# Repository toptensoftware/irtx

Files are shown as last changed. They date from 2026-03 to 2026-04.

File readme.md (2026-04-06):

# irtx

An open source flexible firmware for ESP32 based Infrared transmitter/receivers.

irtx can act as a dumb blaster:

* Receive IR commands over UDP and transmit using an attached IR transmitter circuit
* Accept either raw timing data, or NEC or Panasonic encoded values
* Pair with up to 4 BLE devices to send keyboard, mouse or consumer control HID packets

irtx can also act as a smart device listening for particular actions and invoking actions

* Decode and match received IR signals (supports NEC and Panasonic protocols)
* Handle input events from GPIO attached buttons and rotary encoders
* Invoke sequences of operations in response to IR or GPIO input actions
* Manage a set of "activities" and switch between them

Configuration by serial, telnet or web.

An accompanying NodeJS library [irtx-node](https://github.com/toptensoftware/irtx-node) can 
be used to programatically control the device (eg: send IR codes).  It also provides
a command line tool for sending IR codes and compiling and uploading activity definitions.

## Devices

* [`blaster`](./blaster) - a simple dumb IR blaster that can be placed inconspicously at the back of a room
  providing a way to blast IR from any Wifi enabled device.

## Building the Firmware

The firmware for the esp32 is an Arduino project.  To build

1. Install the `arduino-cli` tools

2. Install the board

    ```bash
    arduino-cli core update-index --additional-urls https://raw.githubusercontent.com/espressif/arduino-esp32/gh-pages/package_esp32_index.json
    arduino-cli core install esp32:esp32 --additional-urls https://raw.githubusercontent.com/espressif/arduino-esp32/gh-pages/package_esp32_index.json
    ```

3. Install libraries

    ```bash
    arduino-cli lib install "Adafruit NeoPixel"
    arduino-cli config set library.enable_unsafe_install true
    arduino-cli lib install --git-url https://github.com/h2zero/NimBLE-Arduino#nvs-custom-namespace
    #arduino-cli lib install "NimBLE-Arduino"
    ```

    (currently requires a dev branch build of NimBLE)

4. Build

    ```bash
    ./build --build c3
    ```

5. Flash (replace com8 with your serial port)

    ```bash
    ./build --flash c3 com8
    ```

Alternatively, you can build and flash in one command:

```
./build c3 com8
```

The firmware also supportes esp32-c6 by passing "c6" instead of "c3" to the build command.

## Activities

Besides acting as a dumb IR blaster, irtx can also manage a set of "activities". 

The activities system supports:

* A set of devices each with a list of operations for turning the device on and off
* A set of activities each of which defines 
    - a set of required devices (which will be turned on, others will be turned off) 
    - a set of operations to and invoke when the activity is switch to, and away from
    - a set of bindings that map input actions (GPIO or received IR commands) to a 
      sequence of operations.

Available operations include:

- Send an IR code
- Send a Wake on Lan packet
- Make an HTTP GET or POST request
- Send a UDP packet
- Delay
- Set the onboard LED
- Switch activities
- Search for a string in a HTTP GET response
- Perform a conditional set of instructions depending on string match

Unlike device configuration which is done via the console and stored in NVS on the device, activity
definitions are compiled from JSON like definitions and uploaded as binary packed data.

The activity definitions can edited either:

* directly in the web UI, or http://my-irtx/activity-editor
* compiled and uploaded using the [node-irtx](https://github.com/toptensoftware/irtx-node) command line tool.

eg: 
```
npx toptensoftware/irtx-node -h my-irtx activites my-activities.js
```

Here's an example activities configuration file (intended for illustration only)

```js
import { op } from "irtx:binpack";

// IR Codes
let ircodes = {
    tvOn: "NEC:0x20dfb34c",
    tvOff: "NEC:0x20dfa35c",
    volumeUp: "PANA:0x400401000405",
    volumeDown: "PANA:0x400401008485",
    ///etc...
}

// Base URL for Yamaha receiver
const yamaUrl = "http://10.1.1.125/YamahaExtendedControl/v1";

// Main Config
const confg = {
    version: 1,
    devices: [
        { 
            // TV Device
            name: "tv", 
            turnOn: op.sendIr(ircodes.tvOn),
            turnOff: op.sendIr(ircodes.tvOff)
        },
        {
            // Yamaha Receiver Device
            name: "receiver", 
            turnOn: op.httpGet(yamaUrl + "/main/setPower?power=on"),
            turnOff: op.httpGet(yamaUrl + "/main/setPower?power=standby"),
        }
    ],
    activities: [
        {
            name: "off",
            devices: [ /* no devices, turn everything off */ ],
        },
        {
            // Watch TV activity
            name: "watchTv",

            // Required devices
            devices: [ "tv", "receiver", ],

            // Actions to invoke when this activity is activated/deactivated
            //didDeactivate: [ ],
            didActivate: op.httpGet(yamaUrl + "/main/setInput?input=hdmi1"),
            //willActivate: [ ],
            //willDeactivate: [ ],

            // Bindings
            bindings: [
                {
                    // Volume up
                    on: ircodes.volumeUp,
                    do: op.httpGet(recUrl +"/main/setVolume?volume=up"),
                },
                {
                    // Volume down
                    on: ircodes.volumeDown,
                    do: op.httpGet(recUrl +"/main/setVolume?volume=down"),
                },
            ]
        },
        {
            // Activity 2 etc...
        }
    ]
}

// The root configuration must be the default export
export default config;

```

## Writing `activities.js`

Activity configurations are written as ES module JavaScript files.  They can be edited
directly in the built-in web UI at `http://<device>/activity-editor`, or compiled to binary
locally using the `@toptensoftware/binpack` tool (or the `irtx-node` CLI which wraps it).

### Importing helpers

The `binpack.js` schema file (served from the device at `/binpack.js` and mapped to the
module specifier `irtx:binpack` by the toolchain) exports everything you need:

```js
import { op, binding, repeatBehaviour, irEventKindMask, bindingFlags,
         riff, parseIPv4, parseMacAddress } from "irtx:binpack";
```

### File structure

An `activities.js` file must default-export the root configuration object:

```js
export default {
    version: 1,
    devices: [ /* device definitions */ ],
    activities: [ /* activity definitions */ ],
};
```

### Devices

Each device has a name and optional `turnOn` / `turnOff` op sequences.  When switching
activities, the firmware powers devices on and off automatically based on which devices the
old and new activities reference.

```js
devices: [
    {
        name: "tv",
        turnOn:  op.sendIr("NEC:0x20dfb34c"),
        turnOff: op.sendIr("NEC:0x20dfa35c"),
    },
    {
        name: "receiver",
        turnOn:  op.httpGet("http://10.1.1.125/YamahaExtendedControl/v1/main/setPower?power=on"),
        turnOff: op.httpGet("http://10.1.1.125/YamahaExtendedControl/v1/main/setPower?power=standby"),
    },
]
```

`turnOn` and `turnOff` accept either a single op or an array of ops.

### Activities

Each activity declares the devices it needs and optional lifecycle hooks:

```js
activities: [
    {
        name: "off",
        devices: [],               // all devices powered off
    },
    {
        name: "watchTv",
        devices: ["tv", "receiver"],   // referenced by name; others are powered off

        // Lifecycle hooks — single op or array of ops, all optional
        willActivate:   [ /* ops run before devices are powered */ ],
        didActivate:    op.httpGet("http://10.1.1.125/.../main/setInput?input=hdmi1"),
        willDeactivate: [ /* ops run before devices are powered down */ ],
        didDeactivate:  [ /* ops run after leaving this activity */ ],

        bindings: [ /* see below */ ],
    },
]
```

Lifecycle order when switching from A → B:
`A.willDeactivate` → `B.willActivate` → device power changes → `B.didActivate` → `A.didDeactivate`

### Bindings

A binding maps an input event (`on`) to a sequence of ops (`do`):

```js
bindings: [
    {
        on: binding.ir("NEC:0x20df40bf"),         // trigger
        do: op.httpGet("http://...?volume=up"),   // single op or array of ops
    },
]
```

The optional `flags` field accepts values from `bindingFlags`:

| Flag | Meaning |
|---|---|
| `bindingFlags.continue_routing` | Don't stop after this binding fires; continue checking remaining bindings |

#### `binding.ir(code)`

Matches a received IR code.  The `code` string format is:

- `"PROTOCOL:VALUE"` — e.g. `"NEC:0x20df40bf"`, `"PANA:0x400401000405"`
- `"PROTOCOL:MODIFIER+VALUE"` — fires only when `MODIFIER` was received within the last 5 s
- `"*"` — wildcard, matches any received IR code

The returned object can be extended with extra fields:

| Field | Default | Description |
|---|---|---|
| `eventMask` | `press` | Bitmask of `irEventKindMask` values to match |
| `minHoldTime` | `0` | Minimum hold time in ms before the binding fires (0 = immediate) |
| `repeatRate` | `0` | Synthetic repeat interval in ms (0 = natural IR repeat rate) |

```js
{ on: { ...binding.ir("NEC:0x20df40bf"), eventMask: irEventKindMask.press | irEventKindMask.repeat }, do: ... }
```

#### `binding.gpio(pin)`

Matches a button press on the given GPIO pin number (configured with `gpio <pin> pulldown/pullup`).

Extra fields available on the returned object:

| Field | Default | Description |
|---|---|---|
| `eventMask` | `press` | `irEventKindMask.press`, `.repeat`, `.release` |
| `minHoldTime` | `0` | ms held before firing (0 = immediate) |
| `initialDelay` | `0` | ms after press before first repeat (0 = use repeatRate) |
| `repeatRate` | `0` | Repeat interval in ms (0 = no repeat) |

#### `binding.encoder_inc(pin)` / `binding.encoder_dec(pin)`

Matches rotary encoder clockwise (`_inc`) or counter-clockwise (`_dec`) rotation on the
encoder whose A-pin is `pin`.  The optional `minVelocityPeriod` field (ms, default 0) limits
firing to encoder velocities at or below the given period.

### Operations (`op`)

All ops can be used as a single value or inside an array wherever an op sequence is expected.

#### `op.sendIr(irCode, ipAddr?, repeat?)`

Transmits an IR code locally or forwards it to a remote irtx device via UDP.

- `irCode` — `"PROTOCOL:VALUE"` string, e.g. `"NEC:0x20df40bf"`
- `ipAddr` — IPv4 address string `"10.1.1.x"` or integer (default `0` = transmit locally)
- `repeat` — one of the `repeatBehaviour` constants (default `repeatBehaviour.default`)

`repeatBehaviour` values:

| Constant | Behaviour |
|---|---|
| `repeatBehaviour.default` | Block the op queue until the IR transmitter is free, then send a full code frame |
| `repeatBehaviour.sendRepeat` | If the same code is already in-flight, send a NEC repeat frame and unblock; otherwise block |
| `repeatBehaviour.dropIfBusy` | If the same code is already in-flight, discard and unblock; otherwise block |

#### `op.httpGet(url)`

Makes an HTTP GET request to `url`.

#### `op.httpPost(url)`

Makes an HTTP POST request to `url`.

#### `op.sendWol(macaddr)`

Sends a Wake-on-LAN magic packet to the given MAC address (`"AA:BB:CC:DD:EE:FF"` string or
array of 6 bytes).

#### `op.delay(ms)`

Pauses op-queue execution for `ms` milliseconds.

#### `op.led(color)`

Sets the onboard LED to `color` (a packed 32-bit RGB integer).  The optional `period` and
`duration` fields (set directly on the returned object) control blink period and auto-off time.

#### `op.udp(ip, data)`

Sends a raw UDP packet.  `ip` is an IPv4 address string or integer; `data` is a byte array.

#### `op.switchActivity(indexOrName)`

Switches to another activity, referenced by its zero-based index or by name string.

#### `op.match_string(str)`

Searches the body of the most recent HTTP response for `str`.  Sets an internal boolean
register used by `op.if_true`.  Use `op.wait_http()` before this op to ensure the HTTP
response has been fully received before searching.

#### `op.if_true(trueOps, falseOps)`

Branches on the result of the most recent `op.match_string` call.  `trueOps` and `falseOps`
are each a single op or an array of ops.

#### `op.wait_http()`

Blocks the op queue until the most recent HTTP request completes.

### Helper functions

#### `riff(str)`

Encodes a 4-character ASCII string as a little-endian 32-bit FourCC integer (the format used
for IR protocol IDs).  Pass a string (`"NEC "`, `"PANA"`) or an integer (returned unchanged).

#### `parseIPv4(ip)`

Parses a dotted-decimal IPv4 address string into a 32-bit integer.  Pass a string or integer
(returned unchanged).

#### `parseMacAddress(mac)`

Parses a colon-separated MAC address string into an array of 6 integers.  Pass a string or
array (returned unchanged).

### Constants

| Export | Values |
|---|---|
| `irEventKindMask` | `press` (1), `repeat` (2), `long_press` (4), `release` (8) |
| `repeatBehaviour` | `default` (0), `sendRepeat` (1), `dropIfBusy` (2) |
| `bindingFlags` | `continue_routing` (1) |
| `bindingType` | `ir` (1), `ir_any` (2), `gpio` (3), `gpio_encoder` (4) |
| `opId` | Numeric IDs for all op types (normally accessed via the `op` class helpers) |

## Configuring the Device

Wifi needs to be configured through serial terminal program.  Once Wifi is enabled, all other
configuration can be done through serial, telnet or via the built-in web based terminal.

To setup Wifi, use a serial monitor program (eg: [ttsm](https://github.com/toptensoftware/ttsm)) to configure the device.  Use the `setwifi` command to setup connection to your Wifi network.

Alternatively you can configure the device to act as a Wifi Access Point using the `setap` command, 
however since AP mode can only be entered using a boot pin configuration you also need a physical 
button on the device and it needs to be configured using the `gpio` and `setbootpin` commands.

Once Wifi or AP mode is active, you can use telnet or the built-in web UI to configure the rest
of the device using the console commands described below.

## Console Commands

The following console commands are available via serial, telnet or using the web UI.

 *   `name <devicename>`                  - set device name, takes effect after restart
 *   `setwifi <ssid> <password>`          - configure WiFi credentials and reconnect
 *   `setap <ssid> [<password>]`          - configure access point credentials (default password: `irtx`)
 *   `setbootpin <pin> [<pin>]`           - configure pin(s) that trigger AP mode at boot (see below)
 *   `status`                             - show device name, MAC, WiFi, IP, BLE pairing status
 *   `pair <bleslot>`                     - pair a BLE device with a specified slot
 *   `unpair <bleslot>`                   - unpair a BLE device slot
 *   `connect <bleslot>`                  - connect to the paired device for a slot
 *   `led <r> <g> <b>` / `led clear`     - set or clear the user LED colour
 *   `activity <name|index>`              - switch to an activity by name or index
 *   `setdefact <index>`                  - set the default activity loaded on boot (default: 0)
 *   `gpio [<pin> [<pin>] <mode>]`        - show or configure GPIO pins
 *   `verbose on|off`                     - enable or disable verbose logging (persisted across reboots)
 *   `nvsreset`                           - factory reset
 *   `nvsdump`                            - dump keys in NVS
 *   `reboot`                             - reboot the device
 *   `dmesg`                              - displays the message log (up to 50 past logged messages)
 *   `help`                               - list all commands

## Configuring GPIO Pins

By default, no GPIO pins are configured.

To set the status LED neopixel to GRB format on pin 10 (eg: Waveshare C3 zero dev board)

```
gpio 10 grb
```

To set the status LED neopixel to GRB format on pin 8 (eg: Waveshare C6 WROOM dev board)

```
gpio 8 grb
```

To set the pins the IR receiver (eg pin 5) and transmitter (eg pin 4) are connected:

```
gpio 5 irrx
gpio 4 irtx
```

To set a generic button input with pull down:

```
gpio 11 pulldown
```

To set a rotary encoder input, pass the A/B pin pair:

```
gpio 12 13 pulldown
```

Note: button and encoder inputs don't do anything unless also configured in the activities 
configuration to perform operations.

## Access Point Mode

The device can be started in WiFi access point (AP) mode for configuration via telnet or web without
needing to connect to an existing network.

1. Configure the AP SSID (and optionally a password, default is `irtx1234`):

    ```
    setap mydevice-ap
    ```

2. Configure a GPIO pin that will trigger AP mode when held at boot. The pin should also be configured
   as a pullup or pulldown input using the `gpio` command:

    ```
    gpio 9 pullup
    setbootpin 9
    ```

3. Press the attached button while powering on the device. The status LED (if configured) will turn 
   yellow to confirm AP mode is active.

4. On your computer or phone, connect to the WiFi network matching the AP SSID you configured,
   using the AP password.

5. Either: 
    * telnet to `192.168.4.1` to access the device terminal
    * visit `http://192.168.4.1` and use the console tab 

Two pins can be specified with `setbootpin` — both must be pressed simultaneously at boot to trigger
AP mode (useful to avoid accidental triggers).

## Telnet Support

Once wifi is enabled and working you can use telnet (eg: [ttsm](https://github.com/toptensoftware/ttsm)) to configure and monitor the device using the same commands as above.

Note: only one telnet client can connect at a time.

## Pairing BLE Devices

Up to 4 paired BLE devices are supported, but only one can be active at a time.  To pair a device:

1. Connect using a serial monitor program or telnet
2. Type `pair N` and the device will start advertising itself for pairing (eg: type `pair 0` for the first device)
3. Go to the device to be paired and choose to pair it.
4. You should see connected and authenicated messages in the terminal and then a message 
   saying the device has been paired.
5. Pair subsequent devices by typing `pair 1`, `pair 2` and `pair 3`

To test connection, use the `connect N` command.   The paired device should automatically reconnect if available.  Use
`connect -1` to disconnect all devices.  Once all devices are paired it's recommended to test switching the connection
between all devices to ensure everything is setup correctly.

Use the `unpair N` command to unpair a device - you should also unpair from the other device too. (eg: "forget this device", "remove device")

The `status` command shows the public addresses for each of the virtual pairing slots, the address of any paired device and the
connection status.

Note: BLE can be a bit flakey during pairing.  Sometimes you might need to toggle bluetooth on/off on the device being paired
to get it to initially connect.

## UDP Protocol

The following describes the UDP protocol for communicating with the device.

Node.js clients can use the [irtx-node](https://github.com/toptensoftware/irtx-node) library.

### IR Transmit

To transmit an IR signal, send a UDP packet to port 4210 in the following format:

* `uint16_t cmd` - must be 1
* `uint16_t reserved` - unused (used to be device index)
* `uint32_t carrierFreq` - carrier frequency
* `uint32_t gap` - a trailing gap (see below)
* `uint16_t timingData[]` - IR code timing values

(all values are little endian)

The `cmd` value must be 1 and indicates this is an IR transmission packet

The `carrierFrequency` must be `38000` otherwise the packet is ignored (might add support for others later)

The `gap` value is a minimum time (in microseconds) that the 
device will enforce between the end of one transmission and the start of the next.

The `timingData` is an array of microsecond timing values where event indices are pulses and odd indices are spaces.  If an odd number of values is passed an implicit zero gap is appended.

Note: pronto IR code definitions usually include the `gap` as the last space in the timing data. I recommended to pass that last space timing value as the `gap` parameter and set the trailing timing space to 0.

### Connect BLE Device

Before sending HID packets to a BLE device, the device first needs to be connected:

* `uint16_t cmd` - must be 2
* `uint8_t bleslot` - the BLE virtual device slot to connect

Currently there's no network method to check if the connection succeeded.  Use the serial or telnet monitor to check status manually.

### Send BLE HID Input Report

Once a BLE device is connected, HID reports can be sent

* `uint16_t cmd` - must be 3
* `uint8_t bleslot` - the BLE virtual device slot to connect
* `uint8_t reportId` - the kind of hid report to send
* `uint8_t reportData[]` - the actual HID report

The `reportId` and `reportData[]` should be

* `reportId` = 1, `reportData[8]` - keyboard input report
* `reportId` = 2, `reportData[2]` - consumer control report
* `reportId` = 3, `reportData[4]` - mouse input report

The format of the `reportData` is as per the BLE HID spec.  The length of the report data must be correct
otherwise the packet will be dropped (check serial/telnet monitor if packets are not being delivered).

### Transmit IR Code

To transmit an IR signal using a named protocol, send a UDP packet to port 4210 in the following format:

* `uint16_t cmd` - must be 4
* `uint16_t reserved` - unused (used to be device index)
* `uint32_t protocolId` - identifies the IR protocol (see below)
* `uint64_t code` - the IR code value to transmit
* `uint8_t repeat` - if non-zero, sends the protocol's repeat frame instead of a full code frame

(all values are little endian)

The device encodes `code` according to the named protocol and transmits it.  The trailing gap is determined by the protocol definition.

Supported protocol IDs are 4-character RIFF-style codes:

| Protocol | ID bytes (`protocolId` little-endian) | Bits |
|---|---|---|
| NEC | `4E 45 43 20` (`0x2043454E`) | 32 |
| Panasonic  | `50 41 4E 41` (`0x414E4150`) | 48 |

If `repeat` is non-zero and the protocol defines a repeat frame, the repeat frame is sent instead of encoding `code`.  NEC defines a repeat frame; Panasonic does not.

### Switch Activity

Switches the current activity:

* `uint16_t cmd` - must be 5
* `uint32_t activityIndex` - the index of the activity to switch to

### Simulate IR Code

Simulates the receipt of an IR code and dispatches it through the activity system:

* `uint16 cmd` - must be 6
* `uint32 protocol` - riff encoded IR protocol
* `uint64 code` - the IR code
* `uint32` - the event kind  (press, release, see [irEventKindMask](./binpack.js))

## HTTP API

The device runs an HTTP server on port 80. All API endpoints return `text/plain` unless noted.

### `GET /api/status`

Returns a JSON object with the current device status (name, MAC address, WiFi, IP, BLE pairing state). Equivalent to the `status` serial/telnet command.

### `GET /api/dmesg`

Returns the device message log as plain text (up to the last 50 entries). Equivalent to the `dmesg` serial/telnet command.

### `POST /api/command`

Executes a serial/telnet command on the device. The request body is the command string (plain text). Returns the command output as plain text.

```
POST /api/command
Content-Type: text/plain

status
```

### `POST /api/upload?filename=<name>`

Uploads a file and writes it to LittleFS. The file is supplied as a `multipart/form-data` body with a single `file` field. The `filename` query parameter sets the destination path on the device — a leading `/` is added automatically if omitted.

```
POST /api/upload?filename=activities.bin
Content-Type: multipart/form-data; boundary=...
```

### `POST /api/reload-activities`

Reloads `activities.bin` from LittleFS and makes it the active configuration. Call this after uploading a new `activities.bin` via `/api/upload`.

### `GET /<path>`

Serves files in the following priority order:

1. **Built-in web UI** — files compiled into the firmware (gzip-compressed, served from flash)
2. **LittleFS** — user-uploaded files (e.g. `activities.bin`, `activities.js`)
3. **SPA fallback** — `GET`/`HEAD` requests that match no file return `index.html` so the client-side router can handle the URL

MIME types are inferred from the file extension: `.html`, `.css`, `.js`, `.json`, `.txt`, `.xml`, `.bin`, `.png`, `.jpg`/`.jpeg`, `.gif`, `.svg`, `.ico`, `.pdf`, `.gz`, `.zip`. Unknown extensions are served as `application/octet-stream`.

The following files have special meaning:

| File | Location | Description |
|---|---|---|
| `/activities.js` | LittleFS | Source file for the current activity configuration (uploaded for reference) |
| `/activities.bin` | LittleFS | Compiled binary form of `activities.js`, loaded by the firmware at boot and on reload |
| `/binpack.js` | firmware (built-in) | Type definitions used to compile `activities.js` into `activities.bin` (fetched by the CLI at upload time) |

`/activities.js` and `/activities.bin` are kept in sync by the upload workflow — the CLI and web UI both upload both files together and then call `/api/reload-activities`.

## License

This project is licensed under the MIT License - see the [LICENSE](LICENSE) file for details.

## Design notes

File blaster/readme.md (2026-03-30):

# blaster

A simple dumb IR blaster that can be placed inconspicously at the back of a room
providing a way to blast IR from any Wifi enabled device.

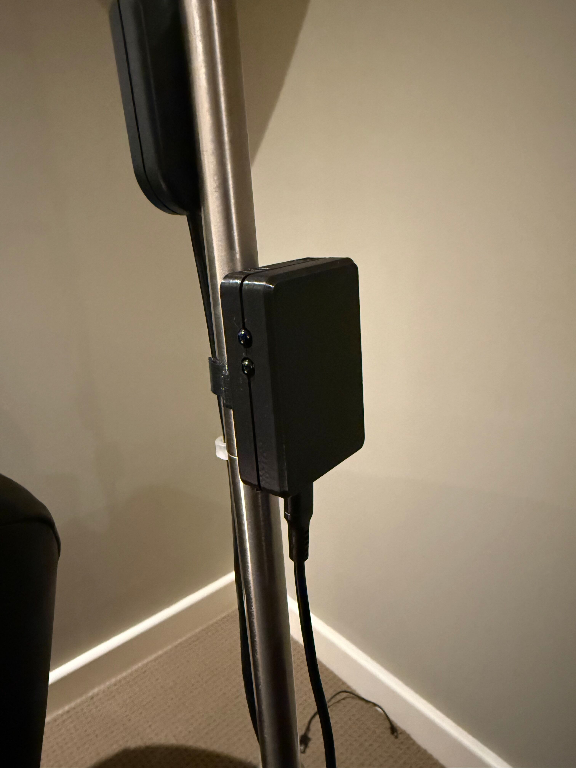
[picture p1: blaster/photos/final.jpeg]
Final


## Build the Circuit

The IR transmitter circuit is easy to build on a small piece of veroboard:

Parts:

* C1 - 100nf ceramic cap
* C2 - 47uF electrolytic cap
* R1 - 680R
* R2 - 22R (or 10R, or 5R)
* BC337 NPN transistor
* 2x IR LEDs (like [these](https://www.jaycar.com.au/5mm-infrared-transmitting-led/p/ZD1945))
* Veroboard 13x8 pins
* [Waveshare ESP32-C3 Zero](https://www.waveshare.com/wiki/ESP32-C3-Zero)

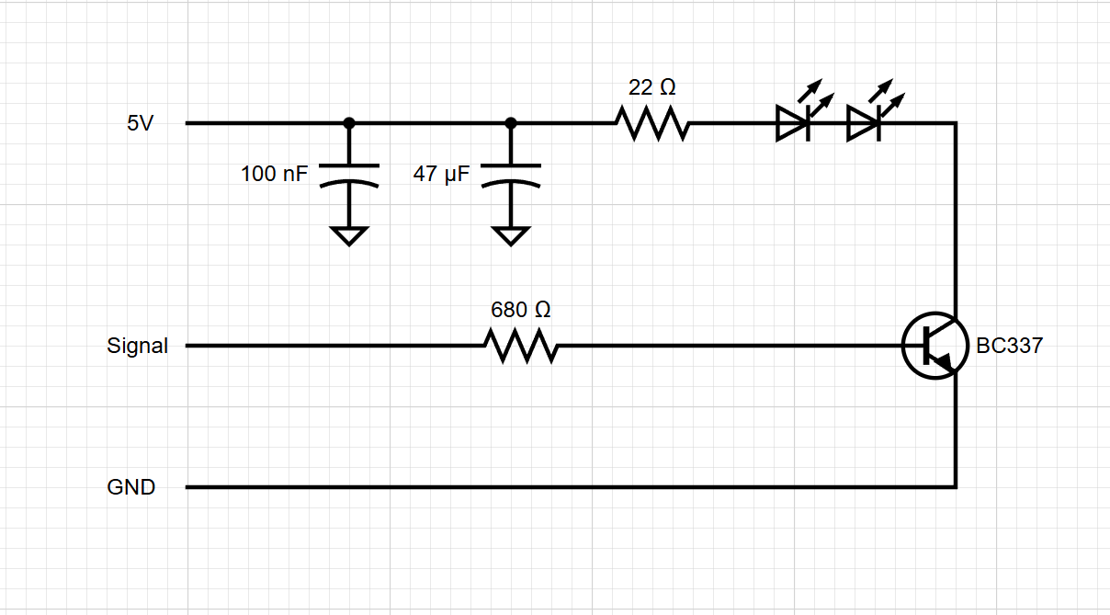
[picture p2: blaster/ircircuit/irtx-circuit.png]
Circuit Diagram


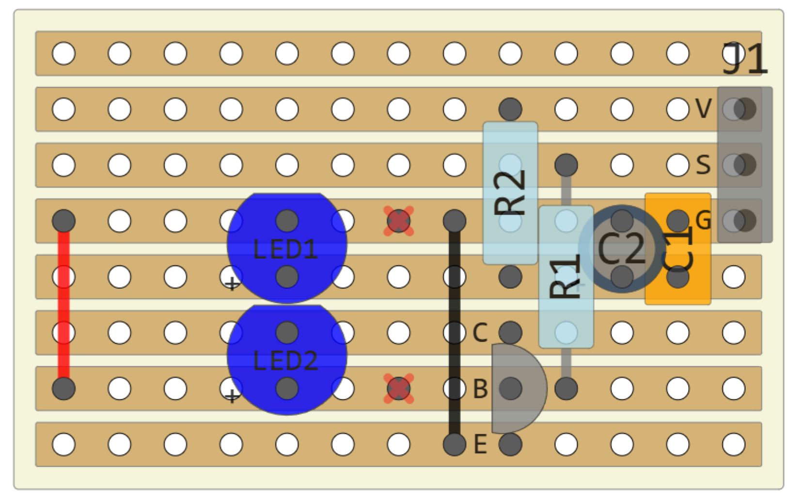
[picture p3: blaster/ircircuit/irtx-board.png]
Veroboard


Notes: 

* the above diagram shows a jumper J1 - it's just for labelling where to solder the wires that go to the ESP32.
* don't forget the two cut tracks indicated by red X
* if I was to rebuild this I'd probably move the red jumper wire at the left to just to the right of the LEDs.
* The leads to C2 need to be bent and the cap "laid down" to fit in the case (see photo below)
* The IR LEDs leads need to be bent so they face out the left side of the diagram. (see photo below)
* Leave the veroboard slightly oversized and file down later to fit the snap-in clips in the case.

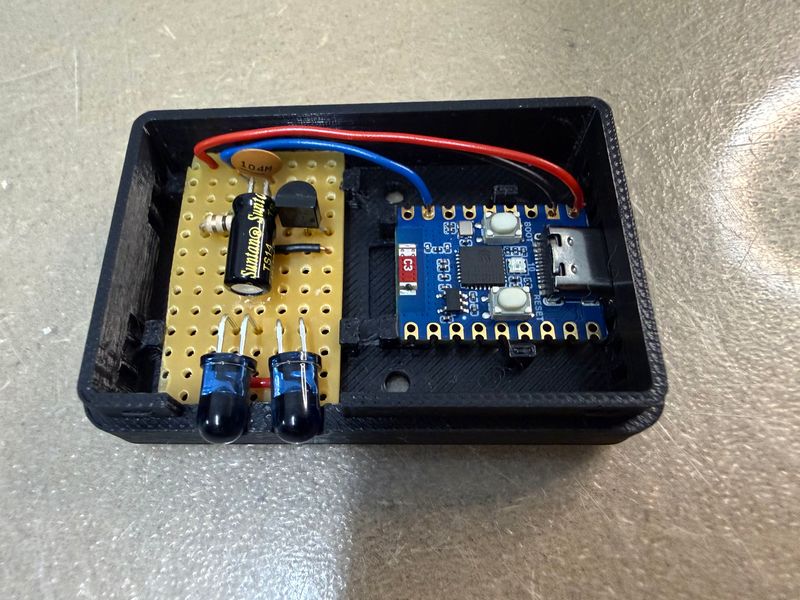
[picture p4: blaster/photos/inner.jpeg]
Inner


## Print the Case

This case supports IR transmitter circuitry only. 

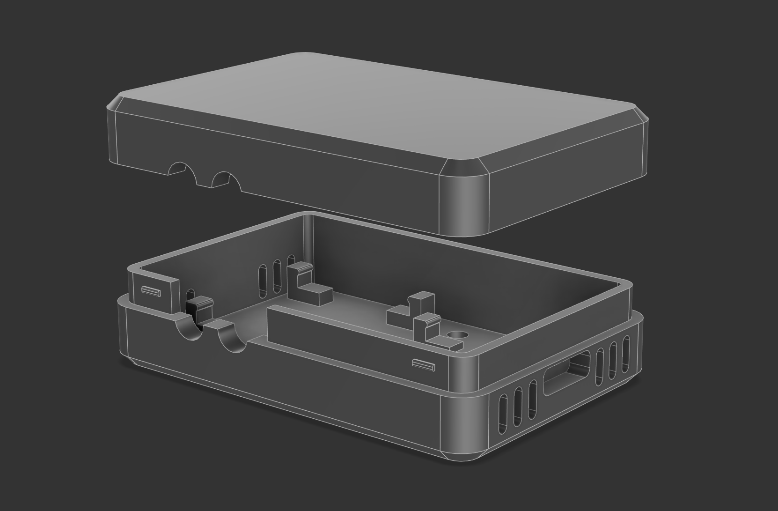
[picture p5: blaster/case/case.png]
case


The case consists of three parts:

* [Top](./case/irtxcase-top.3mf)
* [Bottom](./case/irtxcase-bottom.3mf)
* [Clamp](./case/irtxcase-clamp.3mf)

You'll need a well calibrated printer to get the boards to clip in and the case to snap closed nicely.

The clamp is designed for a 15mm pole and requires:

* two M2.5 heat set inserts 
* two M2.5 6mm screws.

Or, design your own clamp for whereever you want to mount it to. The mounting holds are 26mm center-to-center. 

Fusion and 3mf files are the in the [./case](./case) subdirectory.

I printed the case in PLA, and the clamp in PETG.  You might be able to print it in ABS but I found the board clips too fragile.

## Connect the ESP32

There are three wires from the ESP32 Zero to the IR transmitter circuit.  

* The IR transmitter connection points are shown in the above stripboard image.

* The ESP32 Zero connections are to 5V and GND at the top left and signal to GPIO 4:

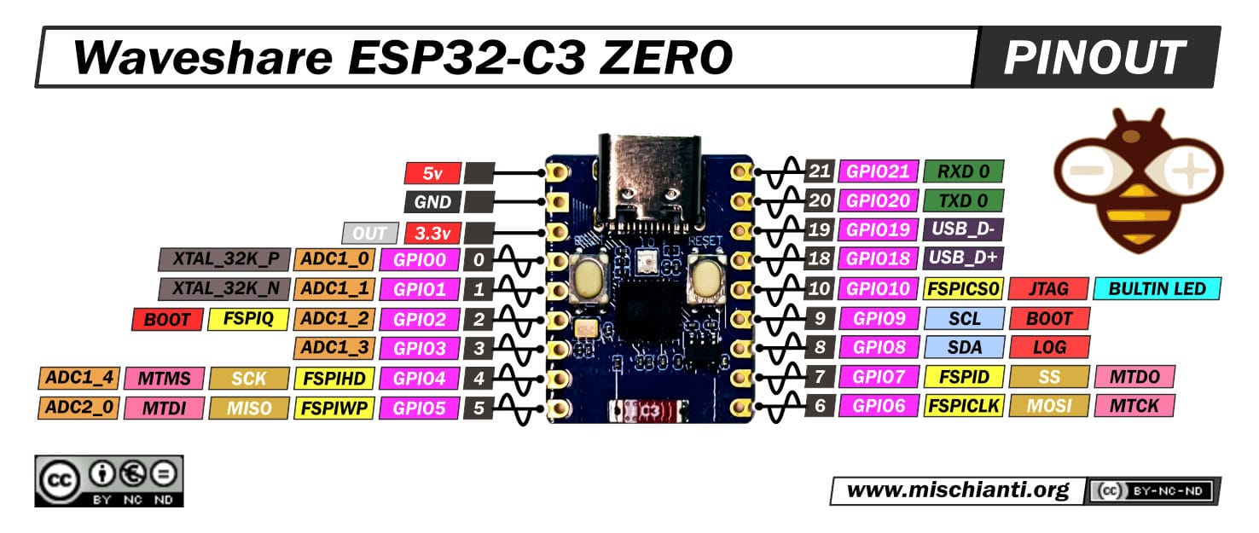
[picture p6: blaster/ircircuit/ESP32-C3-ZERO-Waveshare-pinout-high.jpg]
ESP32-C3-Zero
    

## Configuring the Device

Once the firmware has been built and flashed to the device ([see here](https://github.com/toptensoftware/irtx/#building-the-firmware)) the network
and GPIO pins need to be configured.  Use a serial terminal program (eg: ttsm) to connect
to the device and enter the following commands:

```
setwifi mynetwork mypassword
gpio 10 rgb
gpio 4 irtx
reboot
```

Once rebooted, the onboard LED should show connection status (green if connected).

Test the device by sending IR commands using irtx-node

```
# Send Yamaha receiver power toggle...
npx toptensoftware/irtx-node send NEC:0x7e8154ab
```

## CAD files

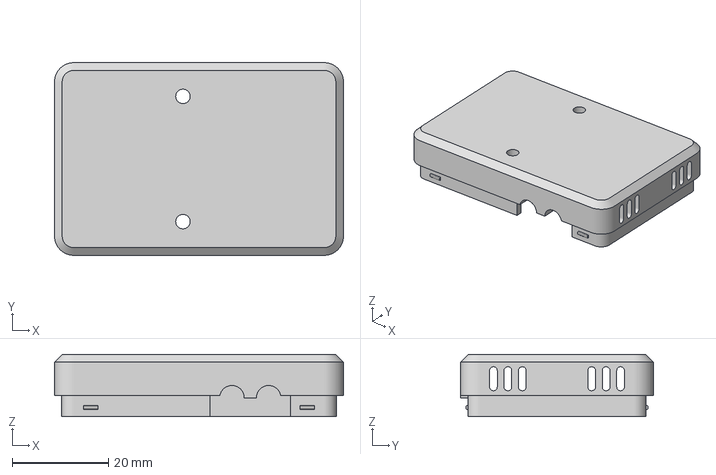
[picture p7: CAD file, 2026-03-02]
blaster/case/irtxcase-bottom.3mf
60.0 x 40.0 x 12.9 mm

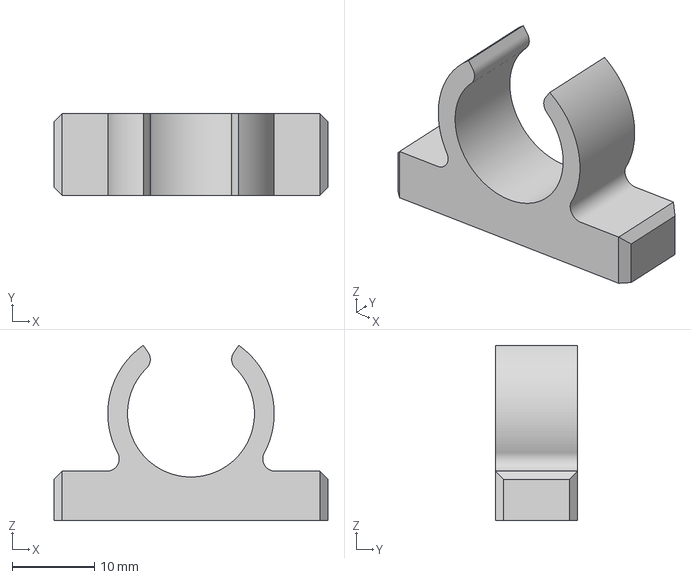
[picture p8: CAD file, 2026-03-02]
blaster/case/irtxcase-clamp.3mf
33.3 x 10.0 x 21.3 mm

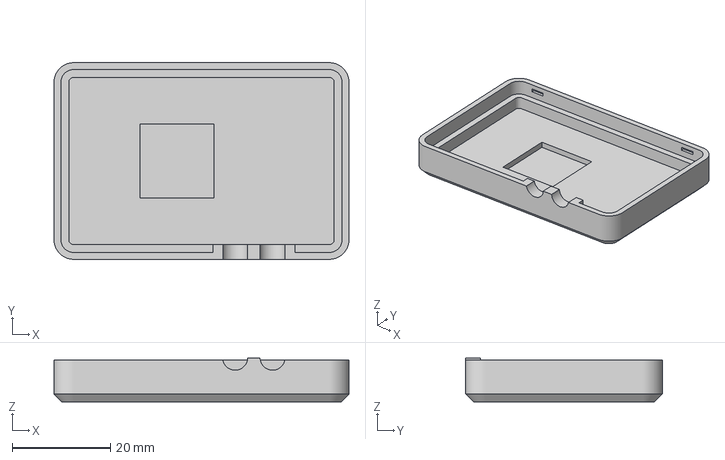
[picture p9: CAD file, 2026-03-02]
blaster/case/irtxcase-top.3mf
60.0 x 40.0 x 8.90 mm

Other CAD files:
blaster/case/irtxcase.f3z

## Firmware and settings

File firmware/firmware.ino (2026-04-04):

/**
 * ESP32 IR Transmitter (WaveShare ESP32-C3 Zero / ESP32-C6)
 *
 * Receives commands over WiFi UDP and either:
 *   - Transmits IR timing sequences via IR LED (RMT peripheral)
 *
 * Hardware:
 *   - IR LED on GPIO 4 (C3) / GPIO 11 (C6)
 *   - Onboard WS2812 RGB LED on GPIO 10 (C3) / GPIO 8 (C6)
 */

#include <WiFi.h>
#include "config.h"
#include "led.h"
#include "device.h"
#include "ir_rx.h"
#include "ir_tx.h"
#include "wifi_udp.h"
#include "console.h"
#include "serial.h"
#include "telnet.h"
#include "ws.h"
#include "ble.h"
#include "filesystem.h"
#include "http.h"
#include "activities.h"
#include "gpio.h"

static SerialConsole  serialConsole;
static TelnetConsole  telnetConsole;
static WsConsole      wsConsole;

void setup()
{
    setLed(LED_PRIORITY_CONNECTIVITY, 0x040200);    // Orange (busy)

    Serial.begin(115200);
    delay(2000);

    // Register consoles before any LOG() calls so output is not lost
    consoleRegister(&serialConsole);
    consoleRegister(&telnetConsole);
    consoleRegister(&wsConsole);

    Serial.println("\n=== ESP32 IR Remote ===");

    setupDeviceName();
    setupGpioConfig();
    setupIrTx();
    setupIrRx();
    setupFs();
    setupActivities();
    setupWifiOrAP();
    setupHttp();
    setupBle();

    // Green = STA connected, Yellow = AP mode
    setLed(LED_PRIORITY_CONNECTIVITY, WiFi.getMode() == WIFI_AP ? 0x040400 : 0x000400);
}

void loop()
{
    serialConsole.poll();
    pollGpio();
    pollIrRx();
    pollIrTx();
    pollWifi();
    pollHttp();
    pollActivities();
    telnetConsole.poll();
    wsConsole.poll();
    pollBle();
}

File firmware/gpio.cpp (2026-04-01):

#include <Arduino.h>
#include "config.h"
#include "gpio.h"
#include "activities.h"

int         gpioIrTxPin    = -1;
int         gpioIrRxPin    = -1;
int         gpioLedPin     = -1;
int         gpioLedOrder   = GPIO_LED_ORDER_GRB;
GpioPinSlot gpioPullupSlots[MAX_GPIO_PULL_PINS]   = {};
uint8_t     gpioPullupCount  = 0;
GpioPinSlot gpioPulldownSlots[MAX_GPIO_PULL_PINS] = {};
uint8_t     gpioPulldownCount = 0;


static void onButton(int pin, bool pressed)
{
    VERBOSE("Button %d %s\n", pin, pressed ? "pressed" : "released");
    invokeGpioBindings(pin, pressed);
}

static void onEncoder(int pin, int direction, uint32_t velocity)
{
    VERBOSE("Encoder %d dir=%+d velocity=%ums\n", pin, direction, velocity);
    invokeEncoderBindings(pin, direction, velocity);
}

// Remove any slot containing pin from both pullup and pulldown lists.
// Also clears irtx/irrx if they match.
static void removePinFromAllRoles(int pin)
{
    if (gpioIrTxPin == pin) gpioIrTxPin = -1;
    if (gpioIrRxPin == pin) gpioIrRxPin = -1;
    if (gpioLedPin  == pin) gpioLedPin  = -1;

    for (int i = 0; i < gpioPullupCount; i++)
    {
        if (gpioPullupSlots[i].pinA == (uint8_t)pin ||
            gpioPullupSlots[i].pinB == (uint8_t)pin)
        {
            memmove(&gpioPullupSlots[i], &gpioPullupSlots[i + 1],
                    (gpioPullupCount - i - 1) * sizeof(GpioPinSlot));
            gpioPullupCount--;
            break;
        }
    }
    for (int i = 0; i < gpioPulldownCount; i++)
    {
        if (gpioPulldownSlots[i].pinA == (uint8_t)pin ||
            gpioPulldownSlots[i].pinB == (uint8_t)pin)
        {
            memmove(&gpioPulldownSlots[i], &gpioPulldownSlots[i + 1],
                    (gpioPulldownCount - i - 1) * sizeof(GpioPinSlot));
            gpioPulldownCount--;
            break;
        }
    }
}

static void saveToNvs()
{
    extern Preferences prefs;
    prefs.begin("gpio", false);
    prefs.putInt("irtx",     gpioIrTxPin);
    prefs.putInt("irrx",     gpioIrRxPin);
    prefs.putInt("led",      gpioLedPin);
    prefs.putInt("ledorder", gpioLedOrder);
    if (gpioPullupCount > 0)
        prefs.putBytes("pullup",   gpioPullupSlots,   gpioPullupCount   * sizeof(GpioPinSlot));
    else
        prefs.remove("pullup");
    if (gpioPulldownCount > 0)
        prefs.putBytes("pulldown", gpioPulldownSlots, gpioPulldownCount * sizeof(GpioPinSlot));
    else
        prefs.remove("pulldown");
    prefs.end();
}

static void initPollState();  // forward declaration — defined below

static void applyPullModes(GpioPinSlot* slots, uint8_t count, int mode)
{
    for (int i = 0; i < count; i++)
    {
        pinMode(slots[i].pinA, mode);
        if (slots[i].pinB != GPIO_PIN_NONE)
            pinMode(slots[i].pinB, mode);
    }
}

void setupGpioConfig()
{
    extern Preferences prefs;
    prefs.begin("gpio", true);
    gpioIrTxPin  = prefs.getInt("irtx",     -1);
    gpioIrRxPin  = prefs.getInt("irrx",     -1);
    gpioLedPin   = prefs.getInt("led",      -1);
    gpioLedOrder = prefs.getInt("ledorder", GPIO_LED_ORDER_GRB);
    size_t upBytes   = prefs.getBytes("pullup",   gpioPullupSlots,
                                      MAX_GPIO_PULL_PINS * sizeof(GpioPinSlot));
    size_t downBytes = prefs.getBytes("pulldown", gpioPulldownSlots,
                                      MAX_GPIO_PULL_PINS * sizeof(GpioPinSlot));
    prefs.end();

    gpioPullupCount   = (uint8_t)(upBytes   / sizeof(GpioPinSlot));
    gpioPulldownCount = (uint8_t)(downBytes / sizeof(GpioPinSlot));

    applyPullModes(gpioPullupSlots,   gpioPullupCount,   INPUT_PULLUP);
    applyPullModes(gpioPulldownSlots, gpioPulldownCount, INPUT_PULLDOWN);
    initPollState();

    LOG("GPIO config: irtx=%d irrx=%d led=%d pullup=%d pulldown=%d\n",
        gpioIrTxPin, gpioIrRxPin, gpioLedPin, gpioPullupCount, gpioPulldownCount);
}

static void printJsonPinArray(GpioPinSlot* slots, uint8_t count)
{
    PRINT("[");
    for (int i = 0; i < count; i++)
    {
        if (i > 0) PRINT(", ");
        if (slots[i].pinB == GPIO_PIN_NONE)
            PRINT("%d", slots[i].pinA);
        else
            PRINT("[%d, %d]", slots[i].pinA, slots[i].pinB);
    }
    PRINT("]");
}

void statusGpioConfig()
{
    PRINT("  \"gpio\": {\n");
    PRINT("    \"irtx_pin\": %d,\n", gpioIrTxPin);
    PRINT("    \"irrx_pin\": %d,\n", gpioIrRxPin);
    if (gpioLedPin < 0)
    {
        PRINT("    \"led_pin\": null,\n");
        PRINT("    \"led_order\": null,\n");
    }
    else
    {
        PRINT("    \"led_pin\": %d,\n", gpioLedPin);
        PRINT("    \"led_order\": \"%s\",\n", gpioLedOrder == GPIO_LED_ORDER_GRB ? "grb" : "rgb");
    }
    PRINT("    \"pullup\": "); printJsonPinArray(gpioPullupSlots, gpioPullupCount); PRINT(",\n");
    PRINT("    \"pulldown\": "); printJsonPinArray(gpioPulldownSlots, gpioPulldownCount); PRINT("\n");
    PRINT("  },\n");
}
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

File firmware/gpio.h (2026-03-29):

#pragma once

#include <stdint.h>

#define MAX_GPIO_PULL_PINS 16
#define GPIO_PIN_NONE      0xFF

struct GpioPinSlot {
    uint8_t pinA;
    uint8_t pinB;   // GPIO_PIN_NONE if single-pin slot
};

#define GPIO_LED_ORDER_GRB 0   // WS2812, WS2812B, WS2813, SK6812 RGB
#define GPIO_LED_ORDER_RGB 1   // WS2811, APA106, PL9823

extern int          gpioIrTxPin;
extern int          gpioIrRxPin;
extern int          gpioLedPin;
extern int          gpioLedOrder;
extern GpioPinSlot  gpioPullupSlots[MAX_GPIO_PULL_PINS];
extern uint8_t      gpioPullupCount;
extern GpioPinSlot  gpioPulldownSlots[MAX_GPIO_PULL_PINS];
extern uint8_t      gpioPulldownCount;

// Override compile-time pin defaults with runtime-configurable variables.
// Any file that needs the actual runtime pin must include this header.
#define IR_TX_PIN gpioIrTxPin
#define IR_RX_PIN gpioIrRxPin

void setupGpioConfig();
void statusGpioConfig();
void gpioSetPin(int pinA, int pinB, const char* func);

void pollGpio();

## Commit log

2026-03-02 Link to esp32 board
2026-03-04 nvsdump, nvsreset, reboot commands, separate bond stores for each virtual device.
2026-03-14 Add IR activities execution engine
    Implements the async activities system with:
    - Op ring buffer (32 slots) processed one per loop() cycle
    - Async execution: instant ops run immediately, timed ops (delay, LED)
    are polled each cycle via s_currentOp until complete
    - switchActivity(): enqueues the full transition sequence
    (willDeactivate → willActivate → device on/off diff → didActivate
    → didDeactivate → commit), rejected if queue is already busy
    - enqueueOps(): appends op pointer arrays to the ring buffer
    - Device on/off tracking via 32-bit mask (max 32 devices); mask
    updated eagerly at enqueue time to avoid redundant on/off ops
    - Binding matcher with two-press modifier suppo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
    [activities.cpp, activities_types.h, ir_rx.cpp]
2026-03-14 Remove IR routing table mechanism
    Routes are superseded by the activities binding system.
    Deleted ir_router.{h,cpp} and removed all call sites:
    - ir_rx.cpp: drop applyRoutes() from onDecoded()
    - serial.cpp: drop statusRoutes() from 'status' command and #include
    - wifi_udp.cpp: drop UDP cmd=5 handler and #include
    https://claude.ai/code/session_011awkFVmPgUBz4LWEi2YqHN
    [ir_rx.cpp, wifi_udp.cpp]
2026-03-14 Add UDP cmd=5 to switch activity by index
    Packet format: [uint16 cmd=5][uint32 activityIndex]
    Reuses the former routing-table command slot.
    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
2026-03-14 Refactor bindings to use polymorphic type system (bindingIr)
    Introduces a virtual `binding` base type with a `type` discriminator
    (mirroring the `op`/`sendIrOp` pattern), and a concrete `bindingIr`
    subtype for IR bindings. Activity bindings field changes from inline
    array (`binding*`) to pointer array (`binding**`) to support future
    binding types (BLE, HID, etc).
    - binpack.js: add `bindingTypeIr` constant; add abstract `binding` base
    with `resolveAbstractType`; rename old `binding` to `bindingIr` with
    `baseType: "binding"`; change activity bindings to `binding**`
    - activities.cpp: update `applyActivityBinding` to check `b->type` and
    cast to `bindingIr*` before accessing IR-specific fi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
    [activities.cpp, activities_types.h, binpack.js]
2026-03-14 Use registerEnum to generate op and binding_type constants in header
    Replace plain JS constants (cmdSendIr, bindingTypeIr etc.) with
    registerEnum("op", ...) and registerEnum("binding_type", ...) so the
    op type and binding type #defines are generated into activities_types.h
    by binpack rather than maintained manually. Move MAX_ACTIVITIES_DEVICES
    to activities.h since it is not a binpack schema value. No changes to
    activities.cpp — generated constant names match the previous manual ones.
    https://claude.ai/code/session_01KdoF9hsUqJyw5SMFJZDqYr
    [activities_types.h, binpack.js]
2026-03-14 docs: add activities system overview to CLAUDE.md
    Covers what activities are, devices, bindings (including the polymorphic
    binding type system), ops, lifecycle hooks, runtime flow, and how binpack
    compiles user-defined JS activities into a packed binary the MCU loads
    directly from LittleFS.
    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
2026-03-14 Move ops list from bindingIr to base binding type
    All binding types need a list of ops to execute when triggered, so ops
    belongs on the base binding struct rather than the bindingIr subtype.
    https://claude.ai/code/session_01FL3CjubDNCZkahWtL339GX
    [activities_types.h, binpack.js]
2026-03-15 Add binding flags with continue_routing support
    - binpack.js: add binding_flags enum (continue_routing=1) and flags uint
    field to the binding base type (default 0)
    - activities_types.h: regenerated — binding now has flags at offset 4,
    BINDING_FLAGS_CONTINUE_ROUTING defined
    - activities.cpp: when BINDING_FLAGS_CONTINUE_ROUTING is set on a matched
    binding, enqueue its ops but continue searching for further matches
    rather than returning immediately; also fixes ops access to use b->ops
    (base binding pointer) instead of bir->ops
    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
    [activities.cpp, activities_types.h, binpack.js]
2026-03-15 Add IR pass-through, string/bool registers, and conditional branching ops
    - New registers: s_irReg (last received IR code), s_stringReg (HTTP response
    body), s_boolReg (string match result)
    - sendIrOp: protocol==0 now uses the IR code register for pass-through
    - httpGetOp: response body stored in s_stringReg
    - New ops: setIrRegOp, searchStringOp, ifTrueOp (with head-injection branching)
    - New binding: bindingIrAny matches any received IR code
    - applyActivityBinding: prepends heap-allocated setIrRegOp before each matched
    sequence; modifier-arm phase moved before wildcard phase so modifier codes
    do not trigger wildcards or set the IR register
    - OP_FLAG_HEAP / OP_CODE: runtime flag for he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
    [activities.cpp, activities_types.h, binpack.js]
2026-03-15 Refactor op dispatch in activities.cpp to use function call tables
    Replace the two switch statements in startOp() and pollCurrentOp() with
    static function pointer tables (s_startOpTable, s_pollOpTable) indexed by
    op code. Each case body is extracted into its own named handler function.
    Both dispatch sites validate that the op code is in range and the table
    entry is non-null before calling. OP_INTERNAL_COMMIT (0xFF) is handled
    before the range check as it sits outside the public table range.
    https://claude.ai/code/session_016r9BD93u5acyzmJj3KnByJ
    [activities.cpp]
2026-03-15 Add suppressRelease() to ir_rx
    Adds a suppressRelease() function that prevents the Release event from
    being fired for the currently held button. Setting the flag clears
    automatically when the button is released (either via timeout in
    pollIrRx or when a new key displaces the active one in onDecoded).
    https://claude.ai/code/session_01MN448P8E2FEDFw5ES2341h
    [ir_rx.cpp]
2026-03-15 Clear suppress_release flag on new press
    Ensures the flag is reset when a new press is registered, guarding
    against any edge case where suppressRelease() was called without a
    subsequent release event clearing it.
    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
    [ir_rx.cpp]
2026-03-15 Add IR event kind filtering to bindingIr
    - Convert IrEventKind enum to power-of-2 bitmask values (Press=1,
    Repeat=2, LongPress=4, Release=8) so event kinds can be OR-combined
    into a mask.
    - Add irEventKindMask enum to binpack.js and a new eventMask field
    (uint, default 0xF = all events) to the bindingIr schema.
    - Update activities_types.h with IR_EVENT_KIND_* defines and the new
    eventMask field in the bindingIr struct (offsets updated accordingly).
    - Update applyActivityBinding signature to accept IrEventKind and skip
    bindings whose eventMask doesn't include the current event kind.
    - Call suppressRelease() whenever a LongPress binding fires, preventing
    the subsequent Release from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
    [activities.cpp, activities_types.h, binpack.js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]
2026-03-15 misc tweaks and fixes
    [activities.cpp, binpack.js, ir_rx.cpp]
2026-03-16 Rewrote binding dispatch, removed ir code device index
    [activities.cpp, ir_rx.cpp, ir_tx.cpp]
2026-03-16 Added led priority
2026-03-16 Make IR transmitter async with two-slot non-blocking design
    Replace blocking delayMicroseconds + rmt_tx_wait_all_done with a
    poll-based state machine. Two slots (in-flight and pending) allow
    one transmission to queue while another is active. Attempts to
    transmit when both slots are full are logged and dropped.
    - Add pollIrTx() driven from the main loop
    - Slot A: tracks RMT_ACTIVE → GAP_WAIT → FREE transitions
    - Slot B: holds pending timings/symbols while slot A is busy
    - Each slot owns its own timings[] and symbols[] buffers
    - Remove the infinite-recursion transmitTimings() stub
    https://claude.ai/code/session_014YDLhNkTeNEhkNetuKYY1B
    [firmware.ino, ir_tx.cpp]
2026-03-16 Simplify async IR TX to single symbol buffer
    Since rmt_new_copy_encoder transfers symbols to RMT memory synchronously
    inside rmt_transmit(), the symbol buffer is free immediately after the
    call returns. There's no need for two symbol buffers or two full slots.
    Replace the two-IrTxSlot design with:
    - One shared s_rmtSymbols[] (built and consumed per-call)
    - s_rmtBusy / s_gapWaiting bools for in-flight state
    - One pending timing buffer (s_pendingTimings[]) for the queued slot
    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
    [ir_tx.cpp]
2026-03-16 Wait for IR TX idle before executing sendIrOp
    Convert startSendIrOp to a timed op: startSendIrOp sets s_currentOp
    immediately and pollSendIrOp spins (returning false) until isIrTxBusy()
    clears, then performs the transmission and returns true.
    Add isIrTxBusy() to ir_tx (true while RMT active, gap draining, or
    pending slot occupied) and register pollSendIrOp in the poll table.
    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
2026-03-16 Drop UDP IR commands while activities op queue is busy
    Add isActivitiesBusy() (true when op queue non-empty or a timed op is
    running) and check it in the UDP dispatcher before handling cmd=1
    (IR timings) and cmd=4 (IR code), logging a drop message if busy.
    Prevents direct UDP IR transmissions from interleaving with an
    in-progress activity op sequence.
    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
    [activities.cpp, wifi_udp.cpp]
2026-03-16 Misc fixes to activity binding match logic
    [activities.cpp, ir_rx.cpp]
2026-03-17 Make HTTP ops non-blocking; add waitHttpOp
    httpGetOp and httpPostOp now spawn a FreeRTOS background task and return
    immediately, so the op queue is never blocked by network latency.
    A new waitHttpOp (op 12) polls until the most recently started HTTP
    request completes, then stores the response body in s_stringReg for use
    by searchStringOp/ifTrueOp chains. Multiple concurrent requests are
    handled via a generation counter: only the latest request's response is
    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
2026-03-17 Add minHoldTime to bindingIr for hold-accelerated bindings
    Tracks how long the current IR button has been held and only fires a
    binding if the elapsed time meets its minHoldTime threshold (default 0,
    preserving existing behaviour). Longer-hold bindings listed first take
    precedence naturally.
    [activities.cpp, activities_types.h, binpack.js]
2026-03-17 Add repeatInterval to bindingIr for synthetic repeat rate control
    On a press binding with repeatInterval set, activities.cpp calls
    setIrRepeatInterval() so ir_rx synthesizes Repeat events at that rate
    instead of the natural IR hardware repeat rate. Real IR repeat frames
    still update last_received_us to keep the held-key state alive but are
    otherwise suppressed while synthetic mode is active. The interval is
    auto-cleared when the key is released.
    [activities.cpp, activities_types.h, binpack.js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]
2026-03-17 Synthetic repeat rates + working on IR receive stability
    [activities.cpp, activities_types.h, binpack.js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]
2026-03-17 Working on activity switching
2026-03-18 Lots of cleanup, fixed modifier not working
    [activities.cpp, activities_types.h, binpack.js]
2026-03-29 Add gpio command to configure IR and pull pins via NVS
    Adds a new serial/telnet command:
    gpio — show current GPIO config
    gpio <pin> <irrx|irtx|pullup|pulldown> — assign a pin role
    IR TX and RX pins default to compile-time values but can be overridden
    from NVS (namespace "gpio"). Pullup/pulldown pins are configured via
    pinMode() on boot. Changes take effect after reboot.
    https://claude.ai/code/session_01DyuMwGduwqaRNbwhaekyAF
    [firmware.ino, gpio_config.cpp, ir_rx.cpp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]
2026-03-29 Remove default IR pin assignments — features disabled until configured
    IR TX and RX are now off (-1) unless explicitly set via the gpio command.
    Removes the chip-specific compile-time defaults entirely.
    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
2026-03-29 Support two-pin slots for encoder pairs in gpio config
    Each pullup/pulldown slot can now hold one or two pins:
    gpio 6 pullup → single-pin slot
    gpio 16 17 pullup → encoder pair (A+B)
    GpioPinSlot struct replaces flat pin arrays; NVS stores 2 bytes per slot.
    Both pins in a slot get the same pinMode applied on boot.
    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
    [gpio_config.cpp]
2026-03-29 Add pollGpio() with button debounce and quadrature encoder decoding
    - Single-pin slots: debounced (10ms) digitalRead, fires onButton(pin, pressed)
    with press level determined by pull direction (pullup=LOW pressed, pulldown=HIGH)
    - Two-pin slots: grey-code quadrature decoder via 16-entry lookup table, fires
    onEncoder(pinA, direction, velocity) every 4 ticks; velocity is the elapsed
    milliseconds across the last 4 ticks measured via circular timestamp buffer
    - Invalid quadrature transitions (noise) are silently ignored
    - Pin states are read at boot to prevent spurious events on first poll
    - onButton/onEncoder are weak stubs (VERBOSE log) that can be overridden
    https://claude.ai/code/sess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
    [firmware.ino, gpio_config.cpp]
2026-03-29 Add bindingGpio — GPIO button bindings in the activities system
    New binding type (type=3) for GPIO pins configured as pullup/pulldown:
    - Matches by pin number and eventMask (press=1, repeat=2, release=8)
    - minHoldTime: binding only fires once button held >= N ms
    - initialDelay: pause after press before first repeat fires
    - repeatRate: interval between synthesized repeat events in ms
    onButton() in activities.cpp overrides the weak stub in gpio_config.cpp
    to route button events into invokeGpioBindings(). Repeat synthesis runs
    in pollActivities() using the same timing infrastructure as IR bindings.
    binpack.js: add gpio:3 to bindingType, gpio:<pin> shorthand in binding
    packMapper, bindingGpi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
    [activities.cpp, activities_types.h, binpack.js]
2026-03-29 Fix GPIO repeat disrupted by release of earlier button
    Releasing a button that isn't the currently-tracked (last-pressed) one
    must not clear s_gpioHoldPin / s_gpioRepeatRate — doing so would kill
    repeat synthesis for the pin still held.
    Also fixes the held duration on release: was using s_gpioPressStartMs
    (overwritten to the last-pressed pin's time); now passes 0 for releases
    of non-tracked pins since minHoldTime on release bindings is rarely used.
    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
    [activities.cpp]
2026-03-29 Add bindingGpioEncoder — encoder bindings in the activities system
    New binding type (type=4) matching on encoder A-pin, direction, and speed:
    - pin: the A-pin of the encoder pair (as configured via 'gpio' command)
    - direction: -1=CCW, 0=any, 1=CW
    - minVelocityPeriod: fires only when velocity(ms) >= this value (0=any)
    Velocity semantics mirror button minHoldTime: a slow spin has a large
    period, so placing slow-only bindings (large threshold) before catch-all
    ones (threshold=0) lets the slow case absorb routing before the fast case
    fires — identical to long-press bindings going before short-press ones.
    binpack.js: add gpio_encoder:4 to bindingType, encoder:<pin>[:<+|->]
    shorthand in bind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
    [activities.cpp, activities_types.h, binpack.js]
2026-03-29 Add 'gpio <pin> rgb' to configure neopixel LED pin at runtime
    LED pin is now NVS-stored (key "led") with no compile-time default.
    setLed() silently no-ops when no pin is configured (gpioLedPin == -1).
    Channel ordering (#ifdef CONFIG_IDF_TARGET_ESP32C6) remains compile-time
    since it reflects the physical LED wiring, not the pin assignment.
    Removes LED_PIN define from config.h entirely.
    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
2026-03-29 Make LED pixel byte order runtime-configurable (grb/rgb)
    'gpio <pin> grb' for WS2812/WS2812B/WS2813/SK6812 (most common)
    'gpio <pin> rgb' for WS2811/APA106/PL9823
    Order stored in NVS key 'ledorder', defaults to GRB.
    led.cpp now uses a runtime branch instead of #ifdef CONFIG_IDF_TARGET_ESP32C6,
    removing the last chip-specific hardcoding from the LED path.
    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
2026-03-29 Add time-based debounce to encoder transitions (2ms)
    Buttons already had a 10ms stable-state debounce. Encoders only had
    grey-code validity filtering. Contact bounce on mechanical encoders
    typically causes rapid back-and-forth transitions within 1-3ms of a
    real detent, registering as spurious ticks.
    Adds lastTransitionMs to EncoderState; valid transitions are ignored
    if fewer than ENCODER_DEBOUNCE_MS (2ms) have elapsed since the last
    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
2026-03-29 strpbrd for smaller tx circuit
2026-03-29 Misc fixes/cleanup for gpio handling
    [activities_types.h, firmware.ino, gpio.cpp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]
2026-03-29 Add gpio pin commands info
2026-03-30 Updated readme, moved blaster device into sub-folder
    [irtxcase-bottom.3mf, irtxcase-clamp.3mf, irtxcase-top.3mf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]
2026-03-30 Updated binpack with binding factory functions
    [binpack.js]
2026-03-30 Fix for encoder_dec
2026-03-30 Better repeat code handling to prevent accumulation of repeated codes in activities op queue
    [activities.cpp, activities_types.h, binpack.js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]
2026-04-01 Add AP mode support: setap command and startAccessPoint()
    - Add NVS storage for AP SSID/password under "ap" namespace (default password "irtx")
    - Add `setap <ssid> [<password>]` terminal command to save AP credentials
    - Add `startAccessPoint()` in wifi_udp.cpp to switch from STA to AP mode
    - Fix `pollWifi()` to skip STA reconnect logic when in AP mode
    - Update `statusWifi()` to show AP SSID and IP when in AP mode
    https://claude.ai/code/session_019i5dYbpghRS4NC94afnhc3
    [wifi_udp.cpp]
2026-04-01 Add setbootpin command and boot-time AP mode trigger
    - Add `setbootpin <pin> [<pin>]` command saving pin(s) to NVS
    - Add `setupWifiOrAP()` which checks boot pin state after GPIO init:
    - If pin(s) are pressed and AP is configured, starts AP instead of STA
    - Respects pullup (active-low) vs pulldown (active-high) from GPIO config
    - Replace `setupWifi()` call in firmware.ino with `setupWifiOrAP()`
    - Update help text
    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
    [firmware.ino, wifi_udp.cpp]
2026-04-01 Fix telnet, HTTP, and UDP to work in AP mode
    - telnet: allow lazy server setup when AP is active (not just WL_CONNECTED)
    - http: allow setup and poll when AP is active
    - UDP: restart udp.begin() after softAP(); restructure pollWifi() so
    UDP packets are still processed in AP mode (reconnect logic skipped)
    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
    [wifi_udp.cpp]
2026-04-01 Set LED yellow in AP mode instead of green
    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
2026-04-01 Allow 0xFF as BLE slot in UDP HID packet to target active connection
    Passing 0xFF skips the slot index and slot-match checks, sending the
    HID report to whatever device is currently connected (or dropping it
    if none).
    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
2026-04-01 Add setdefact command to set default boot activity
    - Store default activity index in NVS under device/defact (default 0)
    - activateInitial() reads it on boot; falls back to 0 if out of range
    - Add `setdefact <index>` terminal command
    - Update help and readme
    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
2026-04-01 Fixes for IR TX log messages over serial
    [ir_tx.cpp]
2026-04-01 Run pack-web.js before Arduino build
    https://claude.ai/code/session_01UYZXzHYo1FBhmorZtCq2Wi
2026-04-01 Add POST /command HTTP endpoint
    Captures all log/print output produced by handleCommand() and returns
    it as the response body. Capture hooks into logWriteRaw() so both
    logWrite and printWrite are captured; output still goes to Serial and
    telnet as normal.
    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
2026-04-01 Rewrite status command to output JSON; add GET /status endpoint
    - log.cpp/h: add printJsonString() — builds an escaped, quoted JSON
    string in a stack buffer and emits via printWrite
    - All status*() functions rewritten to emit their section as a JSON
    object key; each ends with a trailing comma except statusActivities()
    which is always last
    - serial.cpp: wrap status call site with { } so output is valid JSON
    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
2026-04-02 Added ability to upload activities bin + ability to switch activity and set default activity.
2026-04-02 Fix MakeDefault|MakeActive buttons
2026-04-02 Fix using wrong device url in production
2026-04-02 Fix for device URL in dev build
2026-04-05 Add light/dark mode support to xterm console terminal
    Wires the terminal theme into the Stylish theming system so it switches
    alongside the rest of the UI. `#makeTheme()` returns the appropriate
    background/foreground/selection colours for dark or light mode; the
    `darkModeChanged` event listener updates `terminal.options.theme` live
    without requiring a restart. The `.console-page` background now uses
    `var(--body-back-color)` instead of a hardcoded `#000`.
    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
2026-04-05 Fix xterm cursor visibility and stale theme on remount
    - Add `cursor`/`cursorAccent` to both theme objects so the cursor is
    visible in light mode (was hardcoded white, invisible on white bg)
    - Re-apply the current theme in the `else` branch of `onMount` so that
    theme changes made while the console page was unmounted are picked up
    when the user navigates back
    https://claude.ai/code/session_01XaGid2FE5i7a87v5W3kxn1
2026-04-06 Add activities.js configuration guide to readme
    Documents the full authoring workflow for activities.js files: file structure,
    devices, activities, lifecycle hooks, bindings (IR, GPIO, encoder), all op
    helpers, and the exported constants and utility functions from binpack.js.
    https://claude.ai/code/session_01DF6HE9Lb2QpGHJeQubrQAo
2026-04-28 Add clearwifi command and remove forced reboot from nvsreset
    - clearwifi: new command that removes WiFi credentials from NVS,
    disconnects, and sets mode to WIFI_OFF so pollWifi() won't retry
    - nvsreset: removes the blocking delay+reboot; WiFi is torn down
    in the command handler instead so the device stays running
    https://claude.ai/code/session_01PWhAn6ghe5EV8rJDDuNBsJ
    [commands.cpp]
2026-04-28 Reset GPIO RAM state after nvsreset
    Calls setupGpioConfig() after NVS erase so it reloads from the now-empty
    partition, resetting all pin assignments and poll state to defaults.
    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
    [commands.cpp]
